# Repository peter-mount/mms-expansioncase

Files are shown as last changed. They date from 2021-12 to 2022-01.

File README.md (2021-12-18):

This is a simple concept of an expansion enclosure for the MISTer Multi System
case.

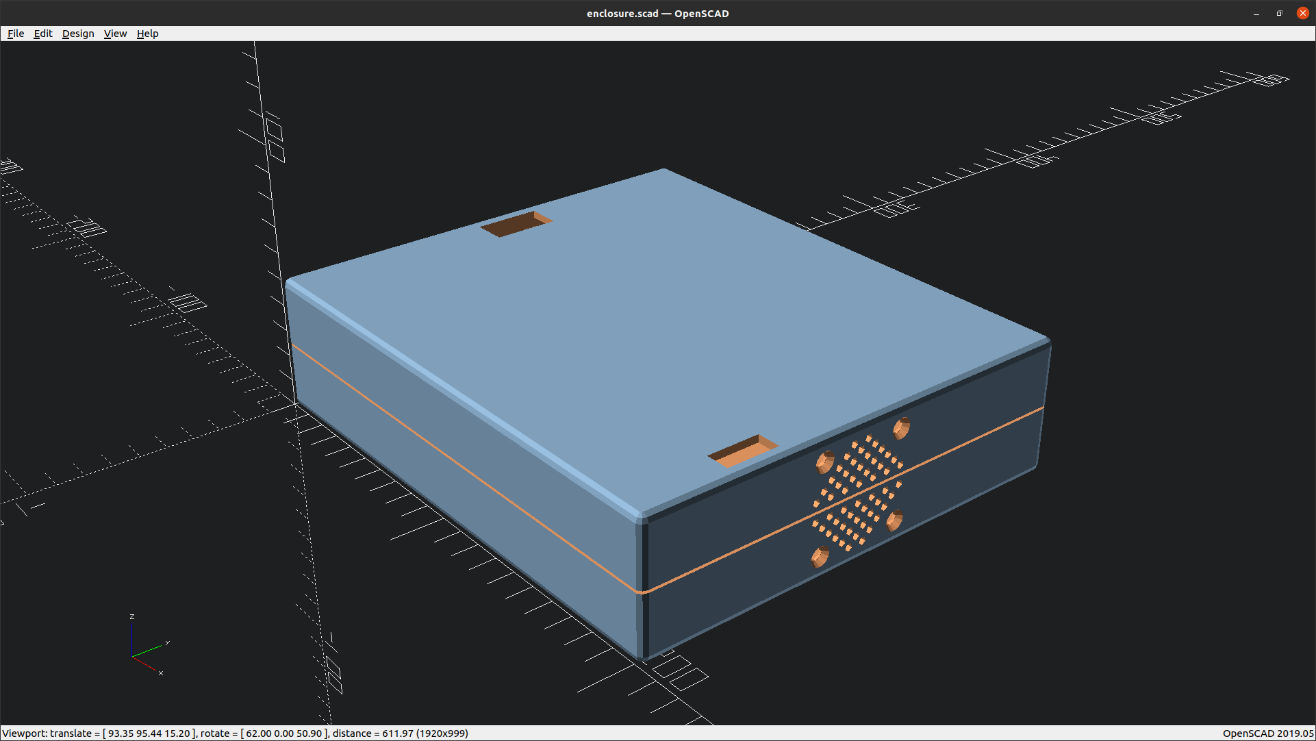
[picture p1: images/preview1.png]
View of just the enclosure


It's designed in OpenSCAD and is intended to sit underneath the MMS case:
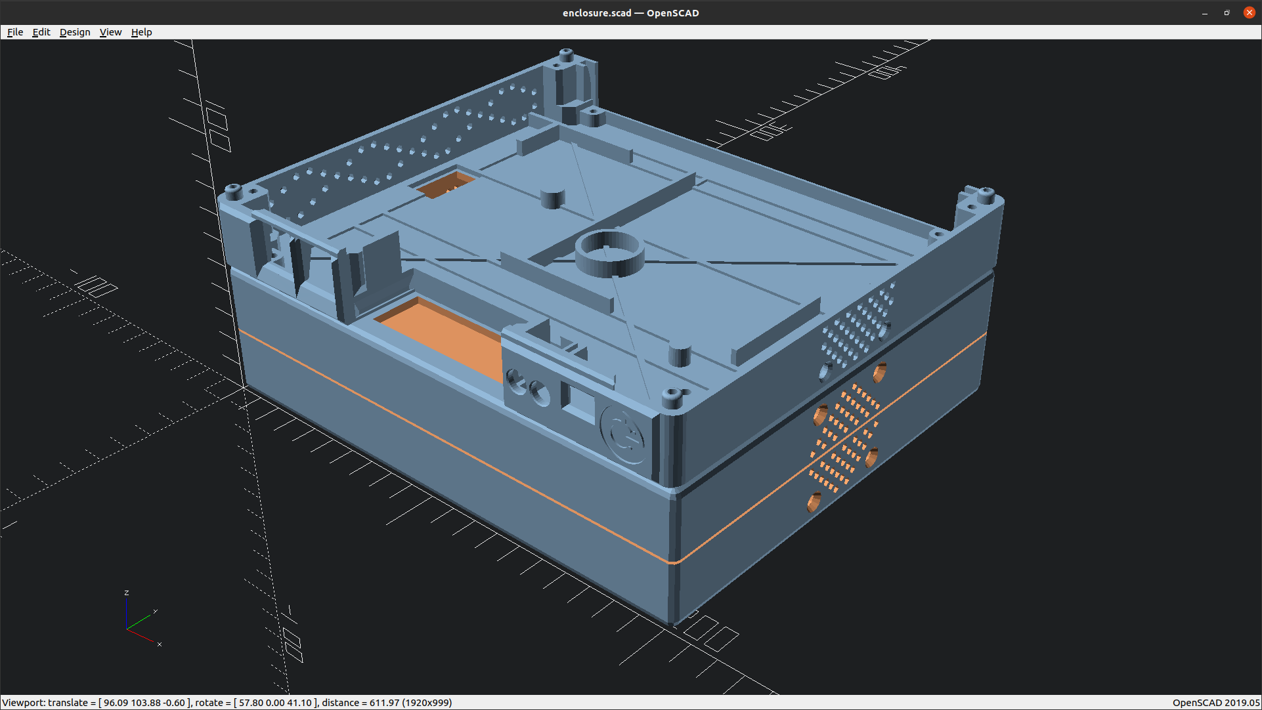
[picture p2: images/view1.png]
Side view with MMS on top


It's configurable for it's height, images above are 50mm and the cutout's on
the top can be turned off if required - the ones here matches those on the MMS case
although there is an additional one for under the SNAC/Dust cover if needed.

There's the option of placing a similar fan to the one in the main case present
and a slot at the back for a backing plate.

# This is a work in progress, so it's not complete in any manner!

## Generating STL's

You need OpenScad installed and on the command line, preferably 2021.01 or later.
Edit the root Makefile and edit the following lines with the location of your install:

    export OPENSCAD      = OpenSCAD-2021.01-x86_64.AppImage
    export OPENSCAD_OPTS = --export-format binstl

Here I have an AppImage in my path so I'm using that directly.

### Using earlier versions of OpenSCAD
You can use versions earlier than 2021.01 but if you do and the build fails due to the
`--export-format` option not being recognised then remove it from `OPENSCAD_OPTS`.
This will, however, mean you are generating Ascii STL's not Binary ones which are
about 5 times the size.

## Running the build

To generate the STL's simply run

    make clean all

All the possible combinations will be generated in the build directory.

### Concurrent renders
This will take a while but if you have the CPU and Memory capacity use the -j option to
make so that multiple renders are done at the same time.

For example:

    make -j8 clean all

will render 8 stl's at the same time.

This will reduce the time taken.
For example a single threaded build takes approximately 10 minutes but on my machine -j32 takes just 36 seconds.

Just make certain the value you pick is less than the number of cores/threads available on your CPU.

## Enclosure

The generated stl's have the following naming convention:

Name of the part, `top` or `base`

Then a `_` delimited list of the options applied.

For example, `top_tc_tp_bf.stl` is the top part with top cutouts, pins & back plate.

These are the current options:

| Option | Description | Applies to |
| --- |---|---|
| tc | Cutout top access points for cables to go though | top |
| sc | Optional cutout under the SNAC port / dust cover | top |
| tp | Add pegs on the top to stop MMS from sliding off | top |
| bc | Optional base access points for cables to go though, for stacking multiple enclosures | base |
| bf | Space for a faceplate at the back | top base |
| ff | Space for a faceplate at the front | top base |

## Face plates

There are currently two faceplate options available:

| Option | Description |
|---|---|
| faceplatePlain.stl | A plain blank faceplate |
| faceplateFlush.stl | A blank faceplate but with the centre raised so the front appears to be flush with the rest of the enclosure |

## Pegs
If you have printed a top with the `tp` option for pegs then you also need to print `pegs.stl` which contains a set of
pegs that will insert into them and prevent the MMS from sliding off the enclosure.

## Customising

### Enclosure height

There's one more configurable setting which is the **external** height of the enclosure.
It defaults to 50mm but if you want to increase that height then edit `global.scad` and change the
`height` variable.

Do not reduce the height below 50mm otherwise the fan will not fit.

All released STL's are with the default height.

### Adding parts

To add custom parts via OpenSCAD code you need to implement the following three modules:

    module enclosureRemoveBefore() {}
    module enclosureAdd() {}
    module enclosureRemoveAfter() {}

These three get called at specific places during constructing the enclosure, but before it is split
into the two halves.

The enclosure is built along the following lines:

    module enclosure() {
        difference() {
            union() {
                difference() {
                    // Outer hull
                    // Cut out inside, fan and grille
                    // back & front faceplate holders
                    // cutouts
                    enclosureRemoveBefore();
                }
                // Add support struts
                // Add internal posts
                enclosureAdd();
            }
            // Remove internal post holes
            enclosureRemoveAfter();
        }
    }

`enclosureRemoveBefore()` is for cutting out anything before the internal features
are added.called first during a difference, so you can use it to remove parts from the enclosure.
`enclosureAdd()` is for adding new internal structures and
`enclosureRemoveAfter()` for any final removals.

#### Example

This example is based on the parts/top_tc_tp_bf.scad generated file but covers the basics:

    // The settings for the standard options, 0=disable, 1=enable
    topCutouts = 1;
    snacCutout = 0;
    baseCutouts = 0;
    topPegs = 1;
    backFaceplate = 1;
    frontFaceplate = 0;

    // Include global.scad and enclosure.scad - change path as necessary
    include <../global.scad>;
    include <../enclosure.scad>;

    // The part to render, either top(), bottom() or plate()
    // If your part exists across both halves then you'll beed to print it
    // once with each.
    top();

    // The hooks, place your code, or references to it in these
    module enclosureRemoveBefore() {
    }

    module enclosureAdd() {
    }
    
    module enclosureRemoveAfter() {
    }

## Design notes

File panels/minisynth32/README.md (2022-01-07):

# Faceplate for the Minisynth 32

This is a custom faceplate to allow the [Minisynth 32](https://github.com/grantek/minisynth32)
to be installed inside our MMS expansion enclosure.

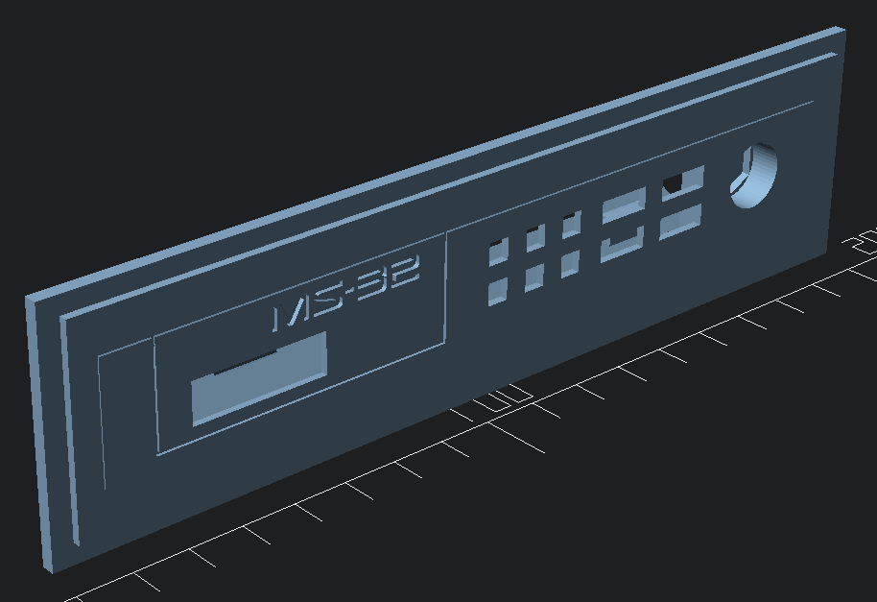
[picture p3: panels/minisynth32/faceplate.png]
MS-32 faceplate


For this to work you need to get [face.stl](https://github.com/grantek/minisynth32/blob/main/3d_models/face.stl)
from that project and save in this directory before opening faceplate.scad in OpenSCAD.

When used with the enclosure it should look like this with the MMS on top.

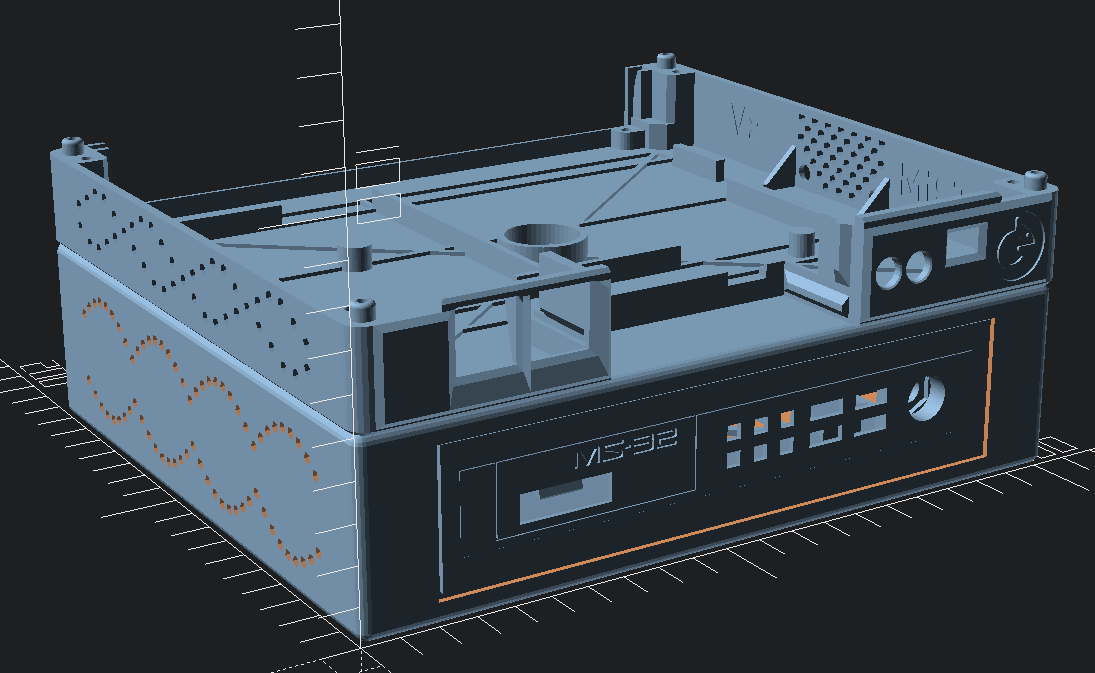
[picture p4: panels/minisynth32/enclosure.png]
MS-32 in the enclosure


Note: This has not been printed, but was done after a thread in the RMC Discord.

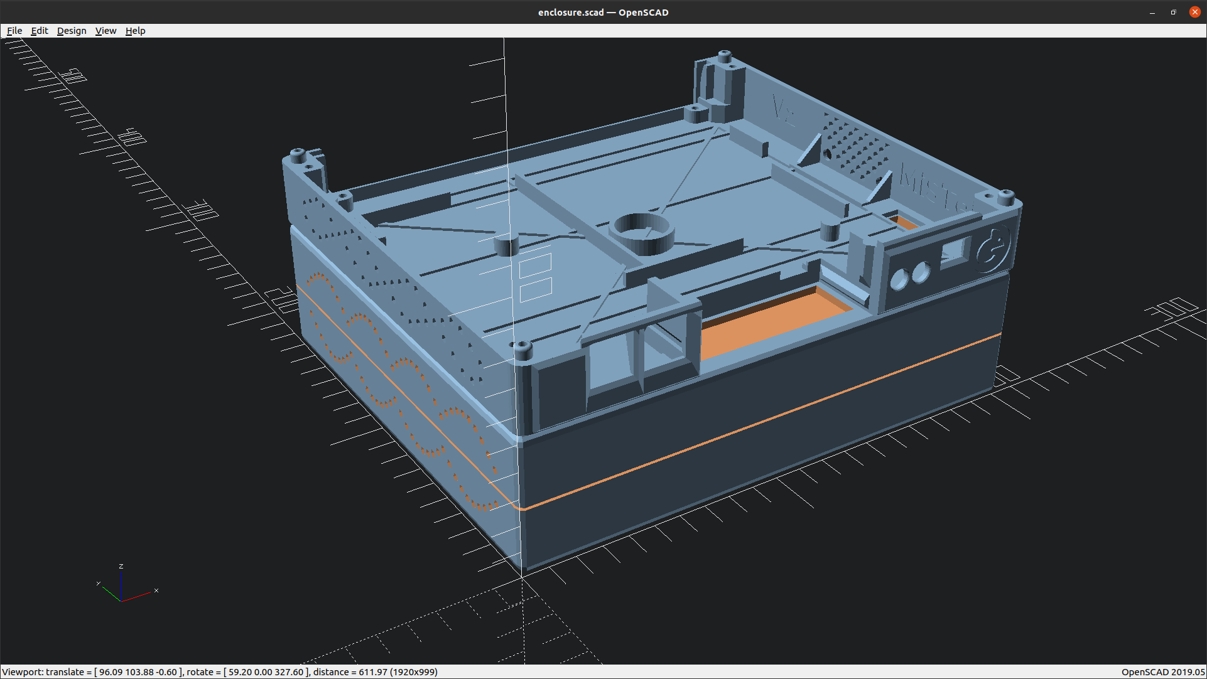
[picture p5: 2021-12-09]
images/view2.png

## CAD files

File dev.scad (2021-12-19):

/*
 * A simple expansion enclosure for the MISTer Multi System (MMS)
 *
 * This is used with openscad to handle the development of the enclosure.
 * It is also the template for the various files to generate the STL's
 */

// Components to view, set to 0 to hide
showTop = 1;        // Show top half of enclosure
showBase = 1;       // Show bottom half of enclosure
showMMSBase = 1;    // Requires part_c_61-23038_1_multisystem_base_3d_rtp.stl but shows it above the top for alignment
showFrontPlate = 0; // Shows front panel if frontFaceplate=1
showBackPlate = 0;  // Shows back plate if backFaceplate=1

separation = 2;     // Separation of components when showing multiple in an exploded view

// Options, set to 1 to enable, 0 to disable
topCutouts = 1;     // Cutout top access points for cables to go though
snacCutout = 0;     // Optional cutout under the SNAC port / dust cover
baseCutouts = 0;    // Optional base access points for cables to go though, for stacking
topPegs = 1;        // Add pegs on top to stop MMS from sliding off
backFaceplate = 1;  // Faceplate at back
frontFaceplate = 1; // Faceplate at front

// Height of the expansion enclosure - this can be adjusted as required.
// Note: this is the external size, internal clearance is 2 * wallThick maximum and that doesn't include any
// internal structures. Minimum is 50mm for the fan to fit
height = 50;

include <enclosure.scad>;

// Show the major components
if (showTop) {
    translate([0, 0, separation]) top();
}

if (showBase) {
    base();
}

if (showMMSBase) {
    translate([221, 67, height + 2 * separation]) import("part_c_61-23038_1_multisystem_base_3d_rtp.stl");
}

if (showFrontPlate && frontFaceplate) {
    translate([17.5, .25+wallThick/2, wallThick+1]) faceplateBlank(1);
}

if (showBackPlate && backFaceplate) {
    translate([17.5, depth-1.25-wallThick, wallThick+1]) faceplateBlank(0);
}

// Empty hooks
module enclosureRemoveBefore() {}
module enclosureAdd() {}
module enclosureRemoveAfter() {}

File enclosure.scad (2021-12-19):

/*
 * A simple expansion enclosure for the MISTer Multi System (MMS)
 */
use <roundedcube.scad>;

// Fixed dimensions of the MMS case
width = 203;
depth = 175;

divideHeight = height / 2;      // Position where the two halves divides

wallThick = 3;                  // Thickness of walls
wallThick2 = wallThick * 2;

width2 = width / 2;             // Half of width
depth2 = depth / 2;             // Half of depth

// Main enclosure
module enclosure() {
    difference() {
        union() {
            difference() {
                // Rounded cube with the rear top & bottom edges flat for belt printers
                hull() {
                    roundedcube([width, depth, height], radius = 3);
                    translate([3, depth - 3, height - 10]) cube([width - 6, 3, 10]);
                    translate([3, depth - 3, 0]) cube([width - 6, 3, 10]);
                }

                // Hollow the hull
                // If we do not have a faceplate visible then the wall needs to be thinner
                translate([wallThick, frontFaceplate?wallThick2:wallThick, wallThick])
                    cube([width - wallThick2,
                            depth - wallThick * (2 + frontFaceplate + backFaceplate),
                            height - wallThick2]);

                // Cutout the fan & grille
                fan();
                grille();

                // Cutout the back plate
                if (backFaceplate) {
                    translate([0, depth - wallThick * 3, 0]) faceplate();
                }
                if (frontFaceplate) {
                    translate([0, - wallThick, 0]) faceplate();
                }

                if (topCutouts) {
                    cutouts(height);
                }

                if (baseCutouts) {
                    cutouts(4);
                }

                if (snacCutout) {
                    // Remove optional front access point under dust cover
                    translate([width2 - 35, 9, height - 5]) cube([70, 20, 5]);
                }

                // Text on inside
                for (y = [20, height - 20]) {
                    translate([wallThick - 1, depth2 - 17, y]) rotate([90, 0, 90]) letter("Area51.dev", 4);
                    translate([wallThick - 1, depth2 + 17, y]) rotate([90, 0, 90]) letter("V1", 4);
                }

                translate([width2, 20, wallThick - 1]) letter("MMS Expansion Unit", 4);

                // Hook to cut out of enclosure
                enclosureRemoveBefore();
            }

            // Support struts, identical on top and bottom
            for (z = [wallThick - 0.2, height - wallThick - 1.5]) {
                translate([0, 0, z]) struts();
            }

            posts(0);

            enclosureAdd();
        }
        posts(1);

        // Hook to cut out of enclosure
        enclosureRemoveAfter();
    }
}

module letter(l, size = 10) {
    // Use linear_extrude() to make the letters 3D objects as they
    // are only 2D shapes when only using text()
    linear_extrude(height = 3) {
        text(l, size = size, font = font, halign = "center", valign = "center", $fn = 16);
    }
}
// Faceplate, normally at the back but can be at the front as well
module faceplate() {
    translate([20, 0, wallThick2]) {
        cube([width - 40, wallThick2 * 2, height - 2 * wallThick2]);
    }
    translate([17, wallThick * 1.5, wallThick * 1.25]) {
        cube([width - 34, wallThick, height - wallThick2]);
    }
}

// Generates two simple faceplates:
// type=0 a simple cube that fits in place
// type=1 A raised section that can be either outside or inside to give extra thickness
module faceplateBlank(type) {
    cube([width - 35, wallThick - .5, height - wallThick2 - 1]);
    if (type) {
        translate([3.75, - 1.5, 3.75])
            cube([width - 41 - 1.5, wallThick - .5, height - wallThick2 - 1 - 6 - 1]);
    }
}

module faceplatePlain() {
    faceplateBlank(0);
}

module faceplateFlush() {
    faceplateBlank(1);
}

// The internal posts for attaching the two halves
module posts(type) {
    if (type) {
        // bolt holes - these match the pegs
        for (x = [6.5, width - 6]) {
            for (y = [11.5, depth - 13]) {
                translate([x, y, - 1]) {
                    // Use h = height + 2 to expose hole through top
                    cylinder(r = 1, h = height - 1, $fn = 16);

                    // Wider on bottom so bolt is shorter & recessed
                    cylinder(r = 3, h = 11, $fn = 16);
                }
            }
        }
    } else {
        // posts
        w = 9;
        d = 16;
        for (x = [2, width - 2 - w]) {
            for (y = [2, depth - 2 - d]) {
                translate([x, y, 1]) cube([w, d, height - 4]);
            }
        }
    }
}

// Top pegs allows the MMS to sit on top but not slide off
// type=1 for a hole, 0 for the peg
module topPegs(type) {
    translate([0, 0, height - 4])
        for (x = [6.5, width - 6]) {
            for (y = [11.5, depth - 13]) {
                peg(type, x, y);
            }
        }
}

module peg(type, x, y) {
    translate([x, y, 0])
        cylinder(r = type?2.8:2.5, h = 8, $fn = 16);
}

module genPegs() {
    for (x = [0, 5]) {
        for (y = [0, 5]) {
            translate([x, y, 0]) peg(0, x, y);
        }
    }
}

// joinPegs adds little pegs to align the two halves
// top==1 for the top hole, 0 for the bottom peg
module joinPegs(top) {
    translate([0, 0, divideHeight - 1])
        for (x = [6.5, width - 6]) {
            for (y = [5.5, depth - 7]) {
                translate([x, y, 0])
                    if (top) {
                        cylinder(r = 3.25, h = 10, $fn = 16);
                    } else {
                        cylinder(r = 3, h = 5, $fn = 16);
                    }
            }
        }
}

// The cutouts matching those on the base of the MMS case
module cutouts(h) {
    // Remove left cable access point
    translate([6, 80, h - 5]) cube([13, 25, 5]);

    // Remove right cable access point
    translate([189, 36, h - 5]) cube([9, 20, 5]);
}

// Struts on the inside of the top & bottom surfaces.
// Partially for strength but also for looks.
// Both are mirrored so some go around non-existend cutouts on the bottom where they appear on the top.
module struts() {

    // The cross struts
    dw = width - wallThick2;
    dh = depth - wallThick2;
    pl = sqrt((dw * dw) + (dh * dh));
    pa = atan2(dw, dh);

    translate([wallThick, wallThick, 0])
        rotate([0, 0, - pa])
            cube([3, pl, 2]);
    translate([width - wallThick, wallThick, 0])
        rotate([0, 0, pa])
            cube([3, pl, 2]);

    // vertical struts
    translate([width2 / 2 + 1, wallThick2, 0]) cube([3, dh - wallThick2, 2]);
    translate([width2 + (wallThick / 4), wallThick2 + 37, 0]) cube([3, dh - wallThick2 - 37, 2]);
    translate([width2 * 3 / 2 + 1, wallThick2, 0]) cube([3, dh - wallThick2, 2]);

    // Horizontal struts
    translate([wallThick, depth2 / 2 - 1, 0]) cube([dw - 15, 3, 2]);
    translate([wallThick + 20, depth2 - (wallThick / 2), 0]) cube([dw - 18 - 25, 3, 2]);
    translate([wallThick, depth2 * 3 / 2 - 2, 0]) cube([dw, 3, 2]);

    // topCutouts
    translate([width - 20, 18, 0]) cube([wallThick, 43, 2]);
    translate([width - 20, 29, 0]) cube([19, 3, 2]);

    translate([23, depth2 - 15, 0]) cube([3, 39, 2]);
    translate([2, depth2 - 15, 0]) cube([23, 3, 2]);
    translate([2, depth2 + 21, 0]) cube([23, 3, 2]);

    // fan mount on the inside of the case
    translate([width - 24.5 - wallThick, depth2, 0]) {
        translate([0, 22, 0]) cube([24.5, wallThick, 2]);
        translate([0, - 22 - wallThick2, 0]) cube([24.5, wallThick, 2]);
        translate([0, - 22 - wallThick2, 0]) cube([wallThick, 50, 2]);
    }
}

// The fan
module fan() {
    translate([width - wallThick2, depth2 - 1, height / 2]) {
        // Screw holes
        m1 = 16.25;
        for (x = [- 1, 1]) {
            for (y = [- 1, 1]) {
                translate([4, m1 * x, m1 * y]) rotate([0, 90, 0]) {
                    cylinder(r1 = 2.5, r2 = 4.5, h = 3);
                    translate([0, 0, - 4]) cylinder(r = 2.5, h = 8);
                }
            }
        }

        // Air holes
        for (z = [1, - 1]) {
            for (y = [1:6]) {
                c = 8 - y;
                dx = (c / 2) * 6;
                for (x = [1:c]) {
                    translate([0, - 4 - dx + (6 * x), 3 * y * z])
                        rotate([0, 90, 0]) cylinder(r = 1.5, h = 8);
                }
            }
        }
    }
}
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

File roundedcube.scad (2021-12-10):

// More information: https://danielupshaw.com/openscad-rounded-corners/
// src https://gist.github.com/groovenectar/292db1688b79efd6ce11

module roundedcube(size = [1, 1, 1], center = false, radius = 0.5) {
    // If single value, convert to [x, y, z] vector
    size = (size[0] == undef) ? [size, size, size] : size;

    translate = (center == false) ?
            [radius, radius, radius] :
                [
                    radius - (size[0] / 2),
                    radius - (size[1] / 2),
                    radius - (size[2] / 2)
                ];

    translate(v = translate)
        minkowski() {
            cube(size = [
                    size[0] - (radius * 2),
                    size[1] - (radius * 2),
                    size[2] - (radius * 2)
                ]);
            sphere(r = radius, $fn=20);
        }
}

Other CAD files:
global.scad
panels/minisynth32/faceplate.scad

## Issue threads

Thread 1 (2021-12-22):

Top pins to hold the MMS are too big & tight

peter-mount, 2021-12-22:
The top pins are slightly too big, so they are very difficult to fit in the existing holes in the MMS case.

To fix:

- Make the pins with a slightly smaller radius

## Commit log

2021-12-09 Add fan & grille
    [enclosure.scad]
2021-12-09 Start of rear plate
    [enclosure.scad]
2021-12-09 Turn off a couple of settings
    [enclosure.scad]
2021-12-09 Add struts to underside of case
    [enclosure.scad]
2021-12-09 Fix struts l&f, add base cutout option
    [enclosure.scad]
2021-12-09 Add option of pegs on top so MMS doesn't slip off
    [enclosure.scad]
2021-12-09 Add boltholes to mount halves together
    [enclosure.scad]
2021-12-09 Option to have a backplate at the front
    [enclosure.scad]
2021-12-09 Add lip at join between halves
    [enclosure.scad]
2021-12-09 Increase thickness of sides as we now have a lip
    [enclosure.scad]
2021-12-10 The lip join is now optional, done this as a flat base might make printing the top easier, but if someone wants it they can have it
    [enclosure.scad]
2021-12-10 Add makefile to build the various STL's
    [dev.scad, enclosure.scad, global.scad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]
2021-12-10 Binary stl support
2021-12-10 Remove scad files as now generated
    [top_tc_tp_bf.scad, top_tc_tp_ff_bf.scad]
2021-12-10 Generate all possible combinations and build stl's
    [enclosure.scad, global.scad]
2021-12-10 Generate zip & tar files of stl's
2021-12-10 Adjust center vertical strut to account for optional snacCutout
    [dev.scad, enclosure.scad]
2021-12-10 Increase depth of peg hole
    [enclosure.scad]
2021-12-10 Increase surfaces on rounded edges
    [dev.scad, enclosure.scad, roundedcube.scad]
2021-12-10 Make rear bottom edge flat to aid belt printers
    [enclosure.scad]
2021-12-10 Add hooks to allow future customisation
    [dev.scad, enclosure.scad]
2021-12-10 Remove lipJoin as sticking with pegs
    [enclosure.scad]
2021-12-12 Add some text
    [dev.scad, enclosure.scad]
2021-12-12 Change case to unit
    [enclosure.scad]
2021-12-13 Reduce front/rear wall thickness if the faceplate option is not used
    [enclosure.scad]
2021-12-13 Change top pegs to be holes to allow the top to be printed upside down on the printer
    [enclosure.scad]
2021-12-13 Make top rear edge flat like the bottom to aid belt printers
    [dev.scad, enclosure.scad]
2021-12-13 Add initial version of blank face plates
    [dev.scad, enclosure.scad]
2021-12-18 Add face plates to generated stl's
2021-12-18 Change filename of faceplates, add pegs stl
    [enclosure.scad]
2021-12-18 Fix typos
    [enclosure.scad]
2021-12-19 Adjust size of pegs, fix bug where peg holes are not right size as not passing type through
    [dev.scad, enclosure.scad]
2022-01-07 Add Minisynth-32 faceplate
    [faceplate.scad]
